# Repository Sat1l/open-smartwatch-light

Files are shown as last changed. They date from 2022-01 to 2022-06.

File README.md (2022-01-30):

# Open-Smartwatch KiCAD files

Repo for kicad schematic, board and gerber files. This project is in development and is not ready for release. Forked by sat1l with love

# TODO
- [X] add usb type-c
- [X] make esp stick out less from the edge of pcb
- [X] make esp DONT stick out from the edge of pcb
- [X] make free gpio & I2C pins accessible on the back of pcb
- [X] cut edge of the pcb where there is a dislay ribbon (to pcb completely round)
- [X] make files for SMT assembly
- [ ] add logos back to pcb
- [X] add new BOM
- [ ] add custom footprints to footprint library in repo
- [ ] automate generating pcb previews
- [ ] design new 3d case for pcb with sunk-in esp

## Tools

To view/modify the files from this repository, install KiCAD from: [https://kicad.org](https://kicad.org)

## [My Telegram channel](https://t.me/sat1lMakes)

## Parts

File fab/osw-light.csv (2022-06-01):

Comment | Designator | Footprint | LCSC
4.7uF | C1,C2 | Capacitor_SMD:C_0603_1608Metric
4.7u | C16 | Capacitor_SMD:C_0603_1608Metric
0.1u | C3,C4,C8,C9,C11,C13,C14,C18,C22 | Capacitor_SMD:C_0603_1608Metric
100u | C5 | Capacitor_SMD:C_1206_3216Metric
LED_Green | D1 | LED_SMD:LED_0805_2012Metric
USB_C_Receptacle_USB2.0 | J2 | Connector_USB:USB_C_Receptacle_HRO_TYPE-C-31-M-12
2N7002 | Q1 | Package_TO_SOT_SMD:SOT-23
22 | R1 | Resistor_SMD:R_0603_1608Metric
510R | R14 | Resistor_SMD:R_0603_1608Metric
5k | R15 | Resistor_SMD:R_0603_1608Metric
200k | R16 | Resistor_SMD:R_0603_1608Metric
2.2K | R18 | Resistor_SMD:R_0603_1608Metric
220k | R19 | Resistor_SMD:R_0603_1608Metric
5.1k | R2,R3 | Resistor_SMD:R_0603_1608Metric
1M | R22 | Resistor_SMD:R_0603_1608Metric
470R | R4,R13 | Resistor_SMD:R_0603_1608Metric
1k | R6,R7 | Resistor_SMD:R_0603_1608Metric
10k | R8,R9,R10,R11,R17,R21 | Resistor_SMD:R_0603_1608Metric
SW_Push | SW1,SW2,SW4,SW5 | open-Smartwatch:button_side_smd
DS3231MZ | U1 | Package_SO:SOIC-8_3.9x4.9mm_P1.27mm
XC6209 | U10 | Package_TO_SOT_SMD:SOT-23-5
MCP73831T-2ACI_OT | U11 | open-Smartwatch:SOT-23-5
BMA400 | U2 | open-Smartwatch:LGA-12_2x2mm_P0.5mm
GC9A01_IPS_display | U4 | open-Smartwatch:GC9A01_IPS_display
CH340E | U6 | open-Smartwatch:MSOP-10_3x3mm_P0.5mm
ttgo-32-micro | U7 | open-Smartwatch:ttgo-32-micro
TPS2115A | U9 | open-Smartwatch:TSSOP-8_4.4x3mm_P0.65mm

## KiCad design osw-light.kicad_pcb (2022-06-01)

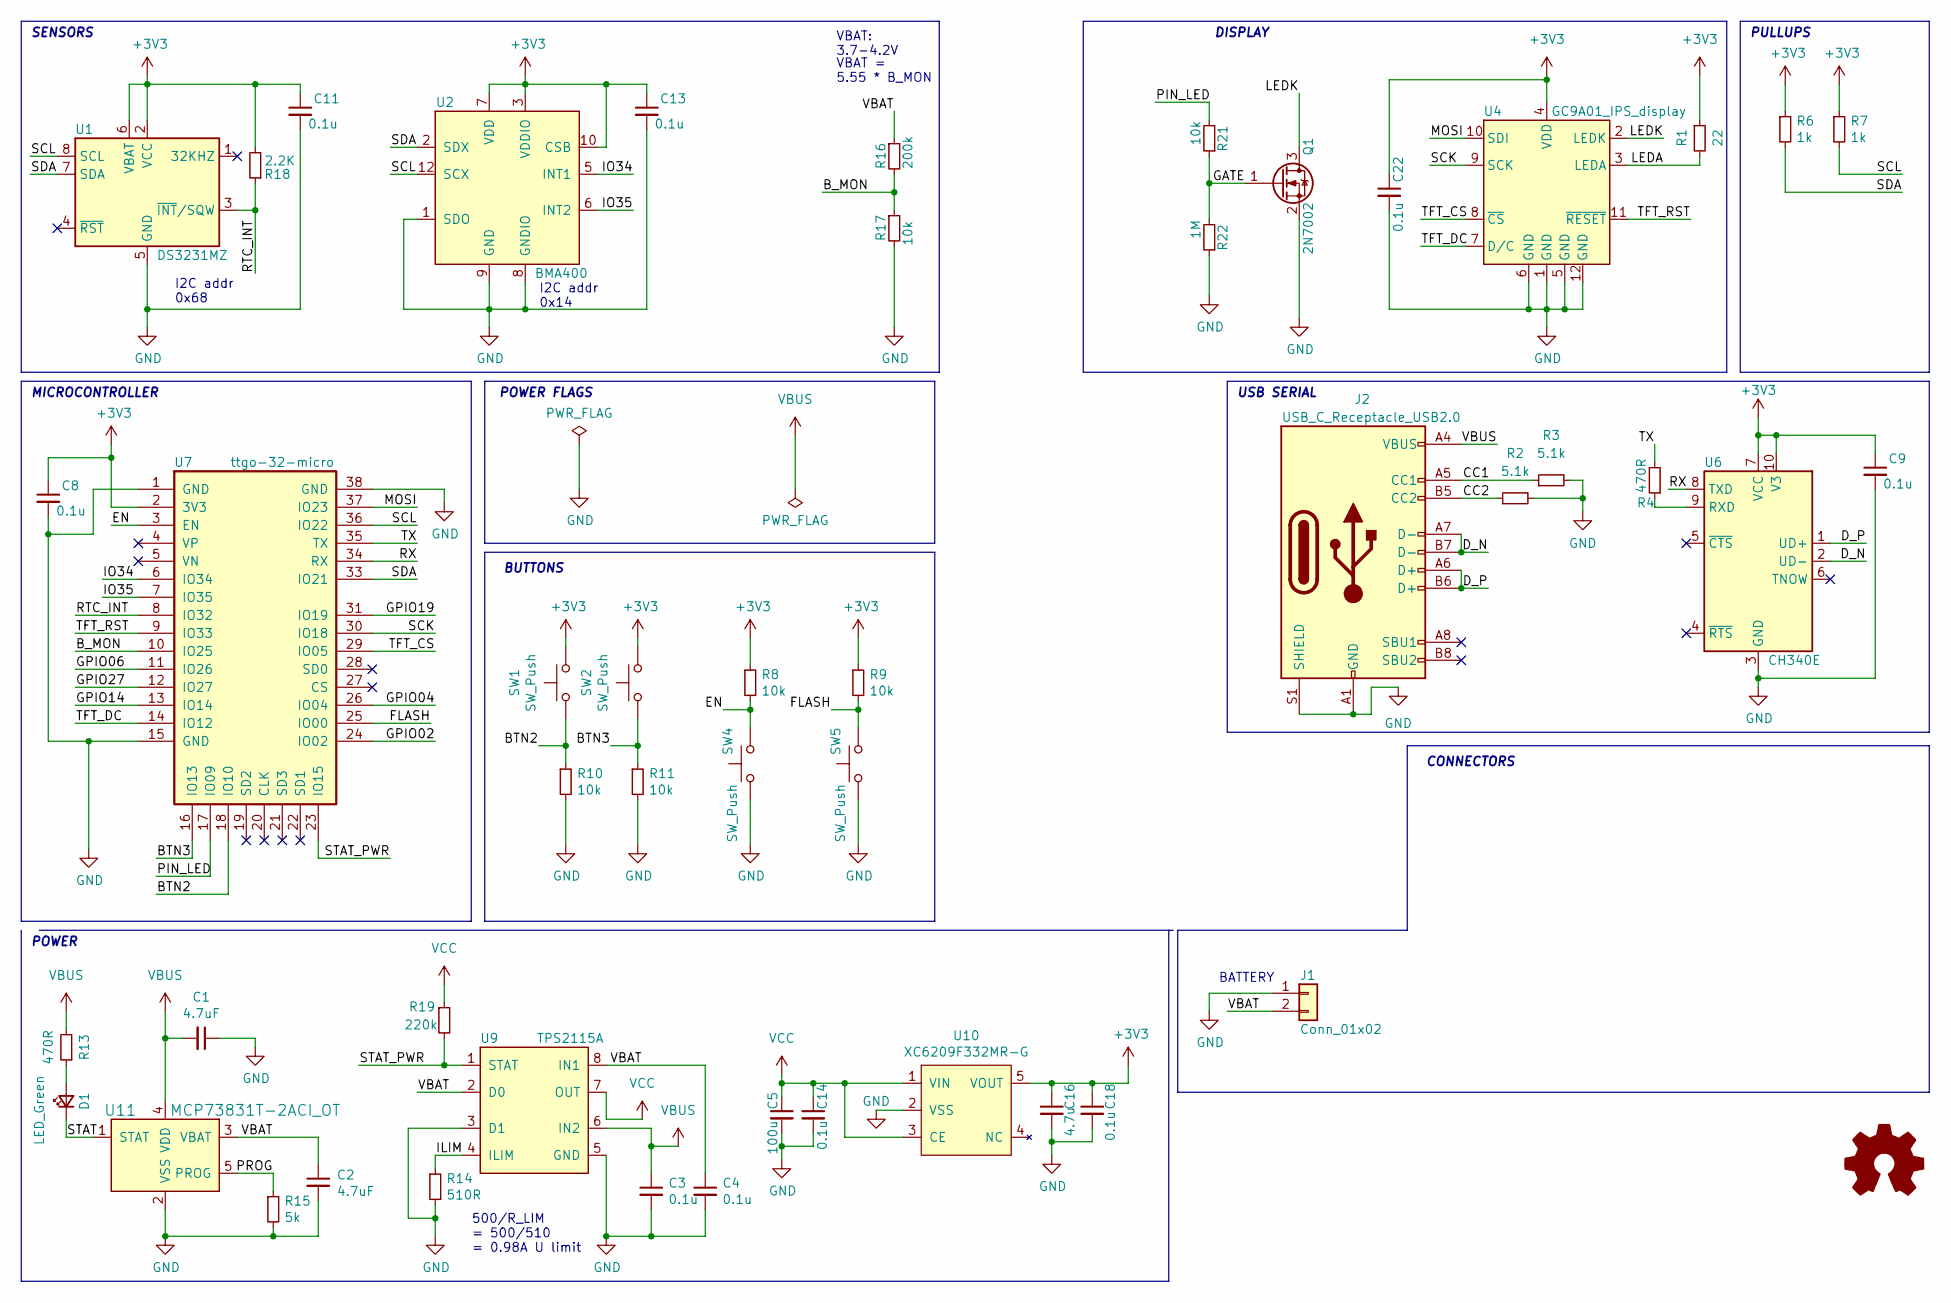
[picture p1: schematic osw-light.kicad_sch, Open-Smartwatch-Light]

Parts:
C1, C2: 4.7uF; C_0603_1608Metric
C3, C4, C8, C9, C11, C13, C14, C18, C22: 0.1u; C_0603_1608Metric
C5: 100u; C_1206_3216Metric
C16: 4.7u; C_0603_1608Metric
D1: LED_Green; LED_0805_2012Metric
J1: Conn_01x02; batteryPads
J2: USB_C_Receptacle_USB2.0; USB_C_Receptacle_HRO_TYPE-C-31-M-12
Q1: 2N7002; SOT-23
R1: 22; R_0603_1608Metric
R2, R3: 5.1k; R_0603_1608Metric
R4, R13: 470R; R_0603_1608Metric
R6, R7: 1k; R_0603_1608Metric
R8, R9, R10, R11, R17, R21: 10k; R_0603_1608Metric
R14: 510R; R_0603_1608Metric
R15: 5k; R_0603_1608Metric
R16: 200k; R_0603_1608Metric
R18: 2.2K; R_0603_1608Metric
R19: 220k; R_0603_1608Metric
R22: 1M; R_0603_1608Metric
SW1, SW2, SW4, SW5: SW_Push; button_side_smd
U1: DS3231MZ; SOIC-8_3.9x4.9mm_P1.27mm
U2: BMA400; LGA-12_2x2mm_P0.5mm; MPN BMA400; DigiKey_PN 828-1081-1-ND
U4: GC9A01_IPS_display
U6: CH340E; MSOP-10_3x3mm_P0.5mm
U7: ttgo-32-micro
U9: TPS2115A; TSSOP-8_4.4x3mm_P0.65mm; MPN TPS2115APWR; DigiKey_PN 296-16940-1-ND
U10: XC6209F332MR-G; SOT-23-5
U11: MCP73831T-2ACI_OT; SOT-23-5; MPN MCP73831T-2ACI/OT; Digi-Key_PN MCP73831T-2ACI/OTCT-ND

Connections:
+3V3: C8.1, C9.1, C11.1, C13.1, C16.1, C18.1, C22.1, R1.1, R6.1, R7.1, R8.1, R9.1, R18.2, SW1.2, SW2.2, U1.2 (VCC), U1.6 (VBAT), U2.3 (VDDIO), U2.7 (VDD), U2.10 (CSB), U4.4 (VDD), U6.7 (VCC), U6.10 (V3), U7.2 (3V3), U10.5 (VOUT)
/BTN2: R10.1, SW1.1, U7.18 (IO10)
/BTN3: R11.1, SW2.1, U7.16 (IO13)
/B_MON: R16.2, R17.1, U7.10 (IO25)
/CC1: J2.A5 (CC1), R3.1
/CC2: J2.B5 (CC2), R2.1
/D_N: J2.A7 (D-), J2.B7 (D-), U6.2 (UD-)
/D_P: J2.A6 (D+), J2.B6 (D+), U6.1 (UD+)
/EN: R8.2, SW4.2, U7.3 (EN)
/FLASH: R9.2, SW5.2, U7.25 (IO00)
/GATE: Q1.1 (G), R21.1, R22.2
/GPIO02: U7.24 (IO02)
/GPIO04: U7.26 (IO04)
/GPIO06: U7.11 (IO26)
/GPIO14: U7.13 (IO14)
/GPIO19: U7.31 (IO19)
/GPIO27: U7.12 (IO27)
/ILIM: R14.1, U9.4 (ILIM)
/IO34: U2.5 (INT1), U7.6 (IO34)
/IO35: U2.6 (INT2), U7.7 (IO35)
/LEDA: R1.2, U4.3 (LEDA)
/LEDK: Q1.3 (D), U4.2 (LEDK)
/MOSI: U4.10 (SDI), U7.37 (IO23)
/PIN_LED: R21.2, U7.17 (IO09)
/PROG: R15.1, U11.5 (PROG)
/RTC_INT: R18.1, U1.3 (~INT/SQW), U7.8 (IO32)
/RX: U6.8 (TXD), U7.34 (RX)
/SCK: U4.9 (SCK), U7.30 (IO18)
/SCL: R7.2, U1.8 (SCL), U2.12 (SCX), U7.36 (IO22)
/SDA: R6.2, U1.7 (SDA), U2.2 (SDX), U7.33 (IO21)
/STAT: D1.1 (K), U11.1 (STAT)
/STAT_PWR: R19.2, U7.23 (IO15), U9.1 (STAT)
/TFT_CS: U4.8 (~CS), U7.29 (IO05)
/TFT_DC: U4.7 (D/C), U7.14 (IO12)
/TFT_RST: U4.11 (~RESET), U7.9 (IO33)
/TX: R4.2, U7.35 (TX)
/VBAT: C2.1, C4.1, J1.2, R16.1, U9.2 (D0), U9.8 (IN1), U11.3 (VBAT)
GND: C1.1, C2.2, C3.2, C4.2, C5.2, C8.2, C9.2, C11.2, C13.2, C14.2, C16.2, C18.2, C22.2, J1.1, J2.A1 (GND), J2.A12 (GND), J2.B1 (GND), J2.B12 (GND), J2.S1 (SHIELD), Q1.2 (S), R2.2, R3.2, R10.2, R11.2, R14.2, R15.2, R17.2, R22.1, SW4.1, SW5.1, U1.5 (GND), U2.1 (SDO), U2.8 (GNDIO), U2.9 (GND), U4.1 (GND), U4.5 (GND), U4.6 (GND), U4.12 (GND), U6.3 (GND), U7.1 (GND), U7.15 (GND), U7.38 (GND), U9.3 (D1), U9.5 (GND), U10.2 (VSS), U11.2 (VSS)
unnamed: D1.2 (A), R13.1
unnamed: R4.1, U6.9 (RXD)
VBUS: C1.2, C3.1, J2.A4 (VBUS), J2.A9 (VBUS), J2.B4 (VBUS), J2.B9 (VBUS), R13.2, U9.6 (IN2), U11.4 (VDD)
VCC: C5.1, C14.1, R19.1, U9.7 (OUT), U10.1 (VIN), U10.3 (CE)

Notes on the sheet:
500/R_LIM = 500/510 = 0.98A U limit
POWER FLAGS
BUTTONS
SENSORS
I2C addr 0x68
CONNECTORS
I2C addr 0x14
POWER
USB SERIAL
DISPLAY
VBAT: 3.7-4.2V
PULLUPS
BATTERY
MICROCONTROLLER
VBAT = 5.55 * B_MON

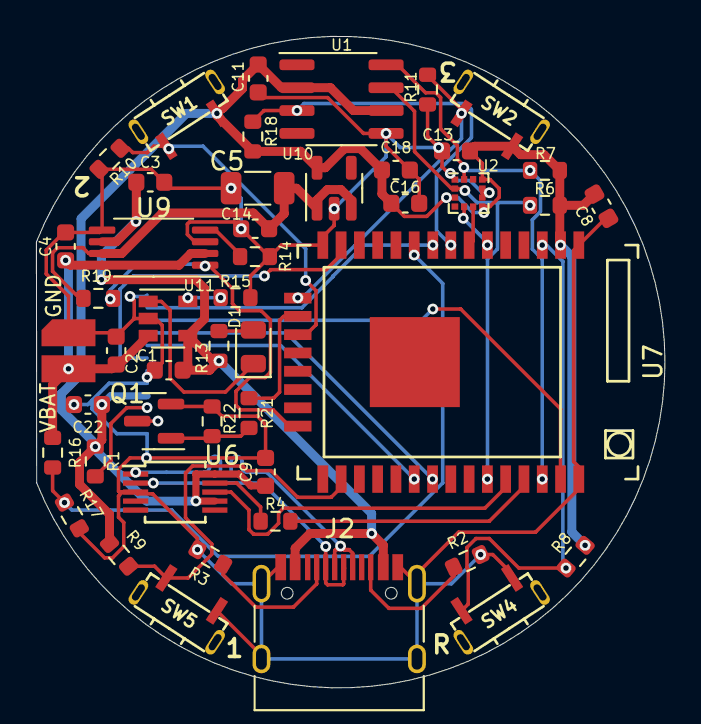
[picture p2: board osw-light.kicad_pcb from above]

Board: 2 copper layers, 34.9 x 36.2 mm, 48 parts (1 on the bottom side), 36 nets.

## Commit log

2022-01-16 added usb support
    [osw-light.kicad_pcb, osw-light.kicad_sch, osw-light.sch]
2022-01-16 some visual changes
    [osw-light.kicad_pcb]
2022-01-16 fixed some footprints and other stuff
    [osw-light-B_Adhes.gbr, osw-light-B_Courtyard.gbr, osw-light-B_Cu.gbl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]
2022-01-16 fixed routes here and there
    [osw-light-B_Courtyard.gbr, osw-light-B_Cu.gbl, osw-light-B_Mask.gbs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]
2022-01-19 Little fixes
    now controller is not sticking out from the cpb, so it's (not)completely round, just before commiting i've realised that there is a display ribbon
    [osw-light.kicad_pcb, osw-light.kicad_sch]
2022-01-30 changed type-c to hro one, added cut on the edge for the display ribbon so everything can fit in r18.1mm circle
    [osw-light-B_Courtyard.gbr, osw-light-B_Cu.gbl, osw-light-B_Mask.gbs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]
2022-02-02 added repo link on the watch
    [osw-light-B_Courtyard.gbr, osw-light-B_Cu.gbl, osw-light-B_Mask.gbs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]
2022-02-02 edit files a bit, also I wanted to learn how to length-match traces, so now data lines are equal length :)
    [bom-2.csv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]
2022-02-06 re-thought some aspects of the pcb and schematics: now there is only one ldo and pcb layout is now better for hand soldering, still needs some cleanup (and bom consolidation)
    [osw-light.kicad_pcb, osw-light.kicad_sch]
2022-02-07 pcb cleanup
    [osw-light.kicad_pcb]
2022-06-01 wow ive did something
    [bom-2.csv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]
